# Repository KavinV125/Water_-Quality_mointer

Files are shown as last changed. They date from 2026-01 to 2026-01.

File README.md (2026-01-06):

# 💧 Water Quality Monitoring System

> **Real-time detection of water contamination using IoT & cloud intelligence**

---
KIT
## 📌 Overview

Ensuring access to **safe drinking water** is a critical challenge for industries, institutions, and communities. Water contamination often goes undetected due to **manual testing, delayed lab reports, or fragmented monitoring systems**.  
This project presents an **IoT-enabled Water Quality Monitoring System** that continuously tracks key water quality parameters and provides instant visibility into water safety.

---

## 🚨 Problem Statement

| Challenge | Impact |
|---|---|
| Manual or periodic testing | Delayed contamination detection |
| No real-time monitoring | Health and safety risks |
| Fragmented data systems | Poor decision-making |
| Compliance difficulties | Regulatory violations |
| Reactive response | Operational losses |

---

## 🎯 Key Water Quality Parameters Monitored

| Parameter | Description | Standard Reference |
|---|---|---|
| **pH** | Acidity/alkalinity of water | WHO / BIS |
| **TDS** | Total dissolved solids | WHO / BIS |
| **Turbidity** | Suspended particles & clarity | WHO / BIS |
| **ORP** | Disinfection effectiveness indicator | AWWA / EPA |
## **PH**
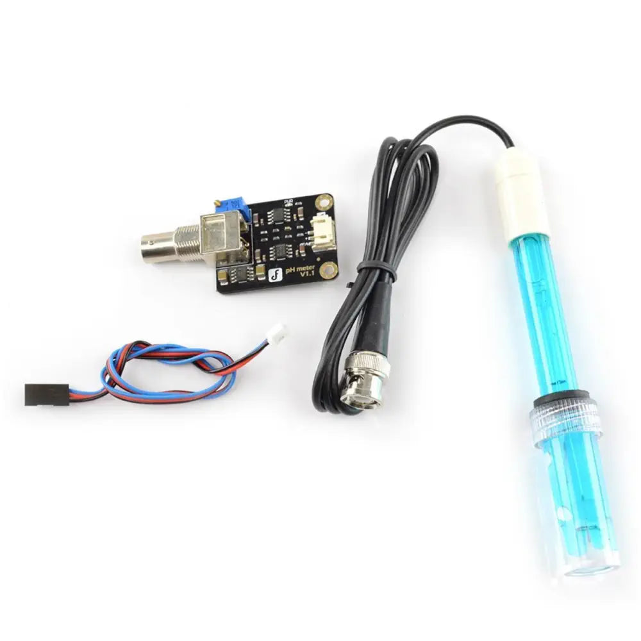
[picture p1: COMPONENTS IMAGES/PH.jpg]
PH


## **TDS**
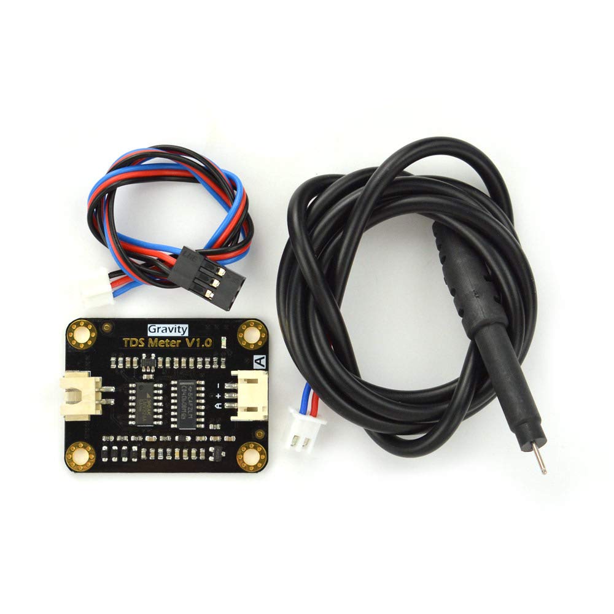
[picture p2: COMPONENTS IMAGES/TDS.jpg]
TDS


## **TURBIDITY**
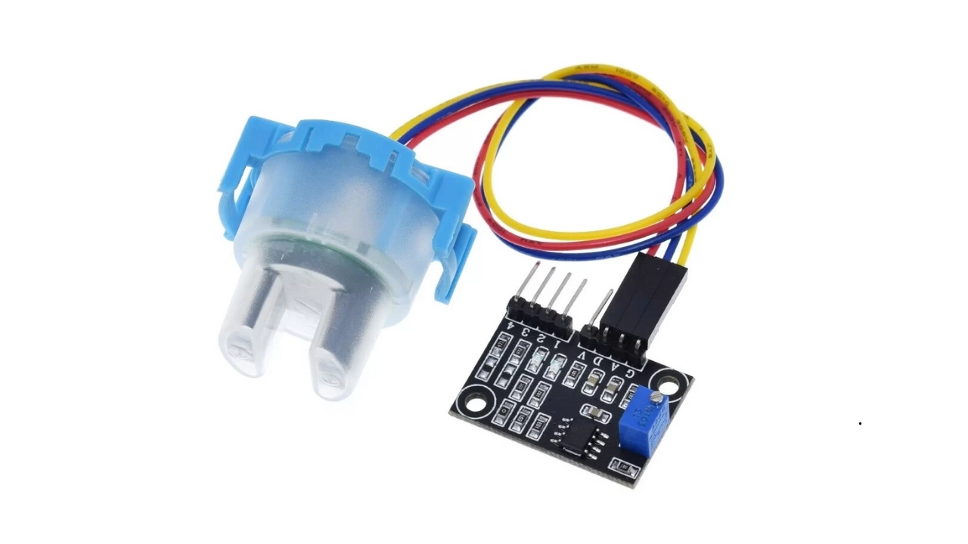
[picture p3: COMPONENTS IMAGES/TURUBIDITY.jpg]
TUR


## **ORP**
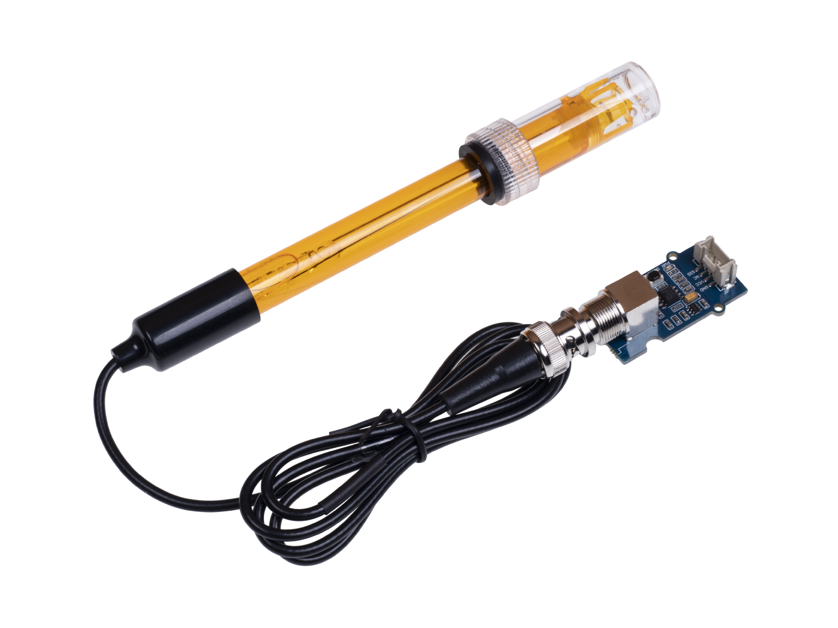
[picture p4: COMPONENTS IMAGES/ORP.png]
ORP


## **RASPBERRY PI 4**

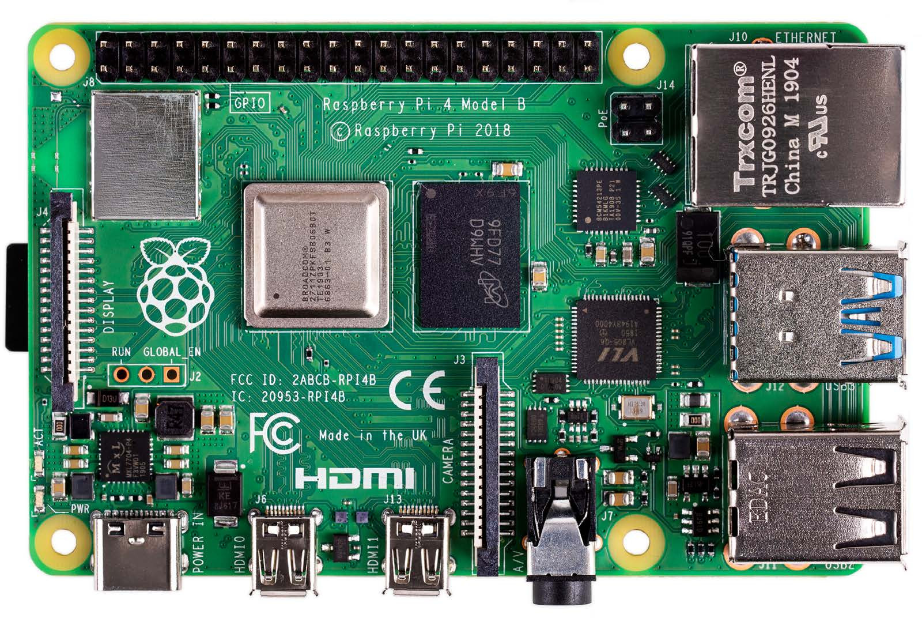
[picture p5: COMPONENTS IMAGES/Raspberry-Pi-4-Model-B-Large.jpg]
PI


## **Sensor placement**
PARAMETERS
---

## 🧠 Concept

The system continuously monitors water quality using **industrial-grade sensors**, processes data using **edge computing (ESP32 / Raspberry Pi)**, and visualizes insights on a **cloud dashboard**.  
Any abnormal value triggers **instant alerts**, enabling proactive intervention.
## **Tech Used :**
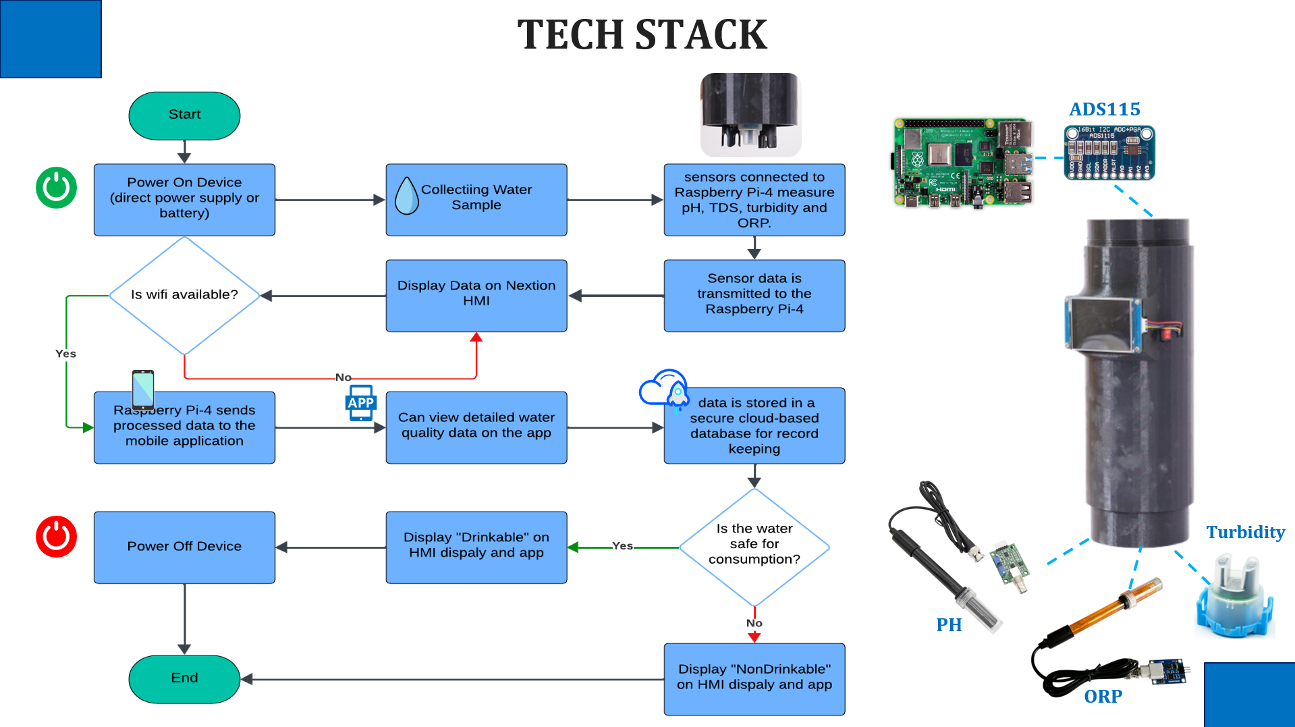
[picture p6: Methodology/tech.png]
TECH

## **Flow**
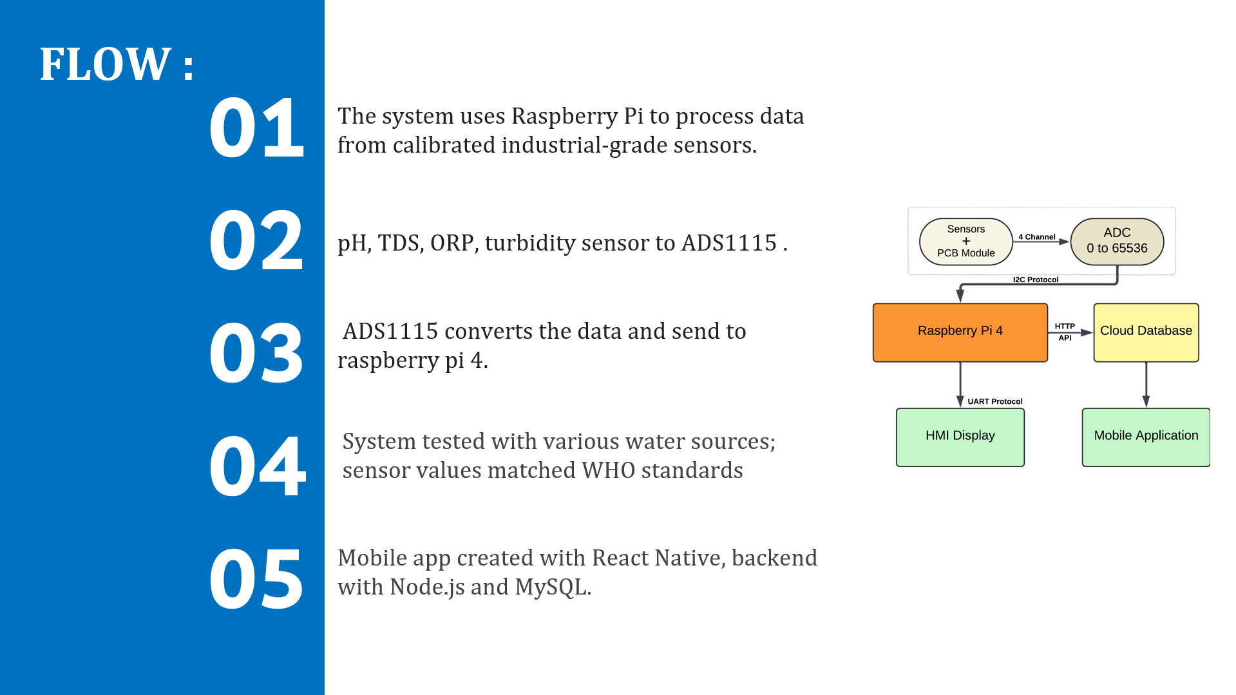
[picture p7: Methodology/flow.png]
flow

---
## **FINAL PRODUCT**
SENSORS

## **OUTPUT**
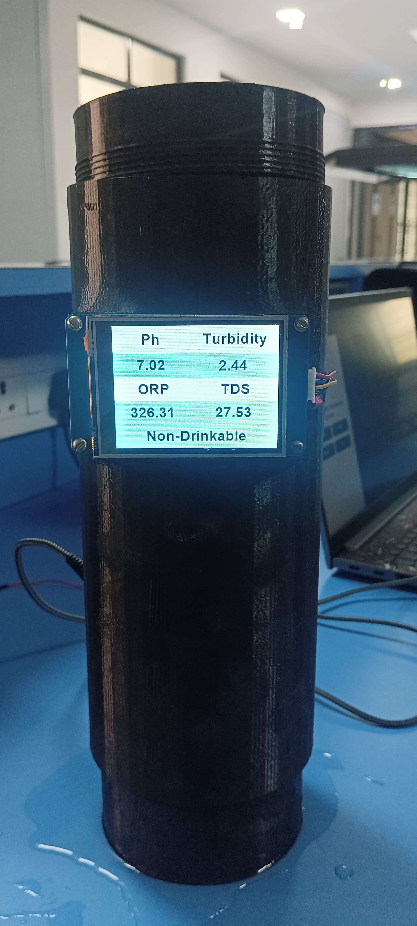
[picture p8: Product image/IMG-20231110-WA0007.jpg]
OUTPUT

## **Web Application UI**

## **Login**
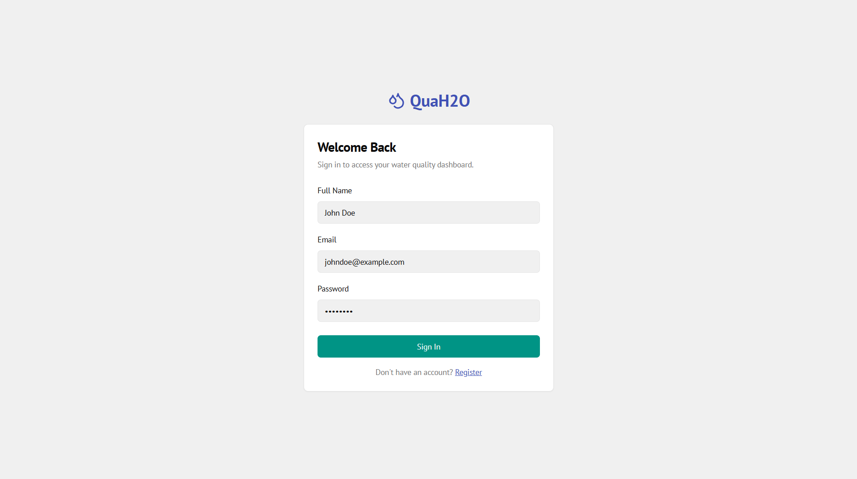
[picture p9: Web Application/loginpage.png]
login


## **Home page**
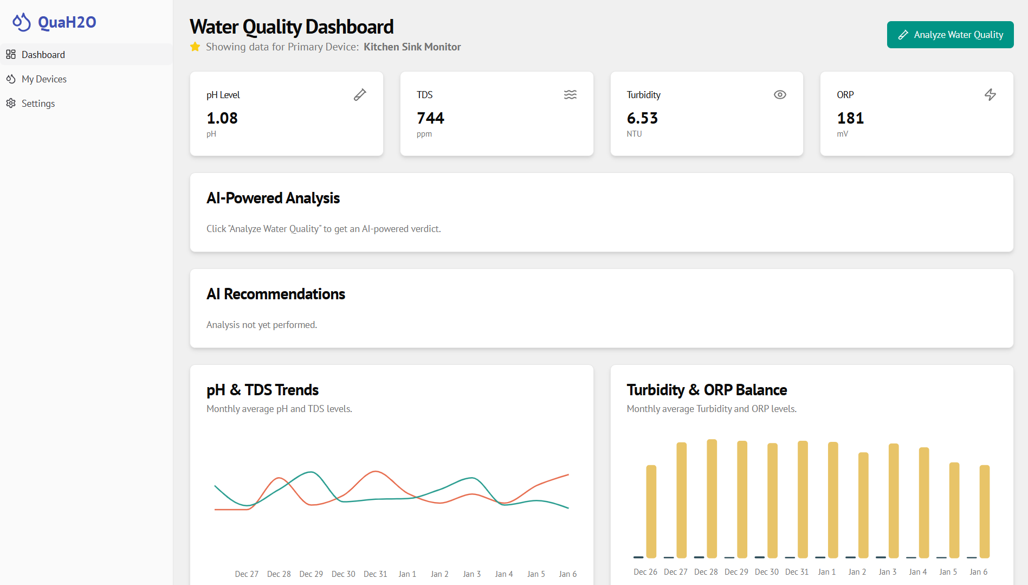
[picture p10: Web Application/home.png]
home


## **Connectivity**
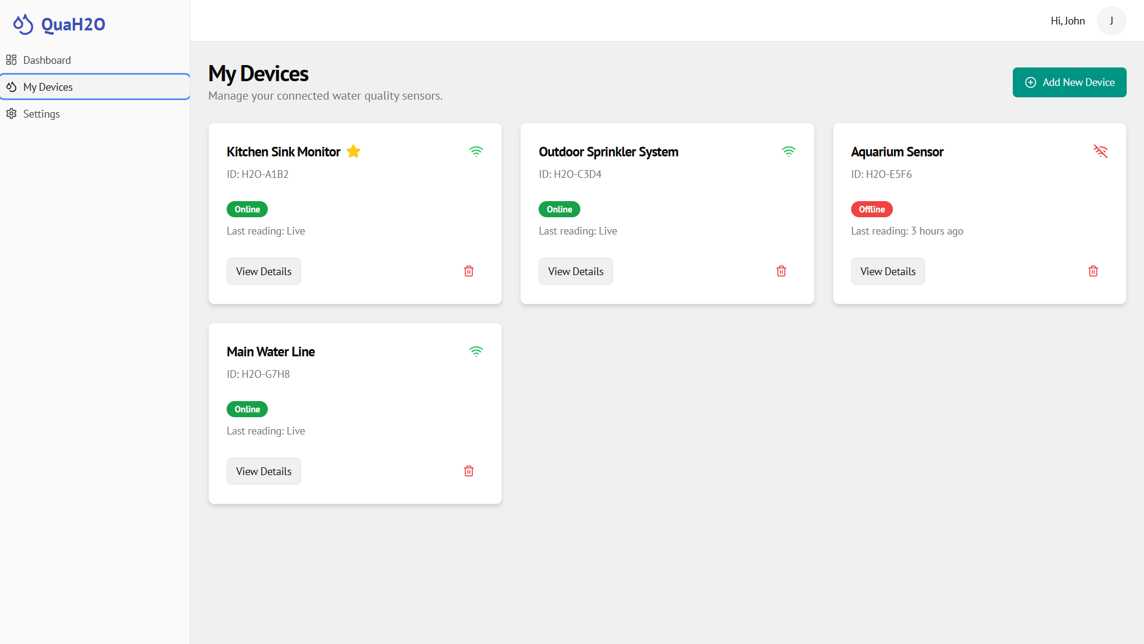
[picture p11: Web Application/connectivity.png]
con

## Final Summary

The Water Quality Monitoring System addresses a critical need for continuous and reliable water safety assurance in both industrial and domestic environments. By combining real-time monitoring of key parameters such as pH, TDS, turbidity, and ORP with IoT-enabled sensing and cloud-based analytics, the system eliminates reliance on slow, manual testing methods. It empowers users to detect contamination instantly, make informed decisions, and maintain compliance with water quality standards. Designed to be scalable, accurate, and user-friendly, this solution contributes to improved public health, operational efficiency, and long-term water sustainability.

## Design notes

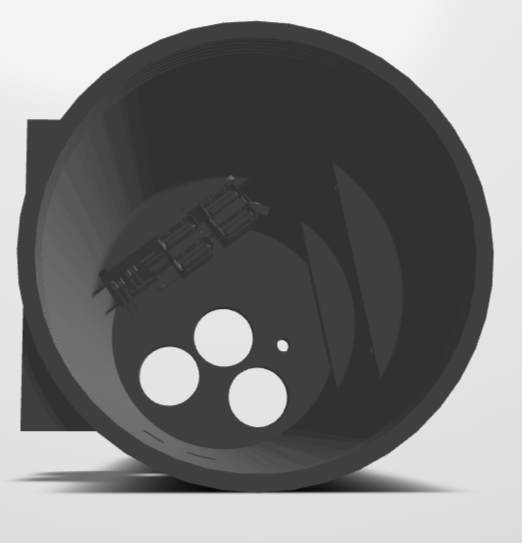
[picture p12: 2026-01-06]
3D Designing/3D image1.png

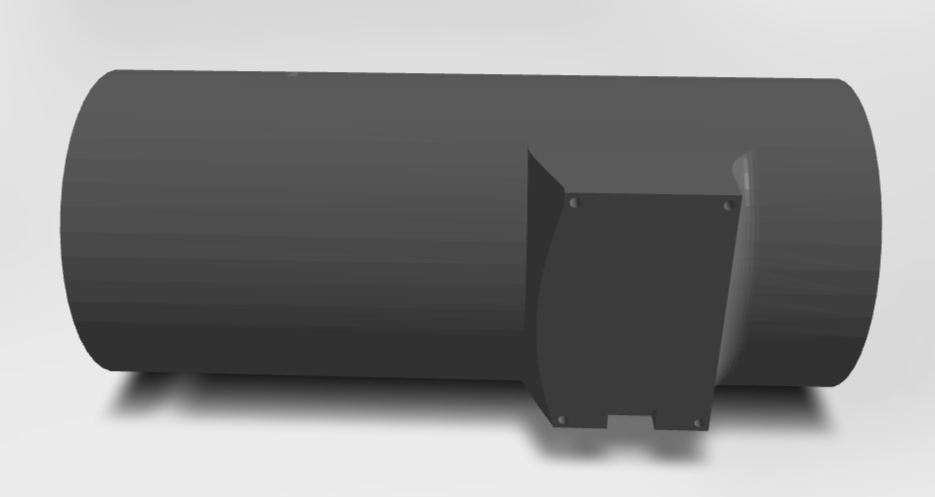
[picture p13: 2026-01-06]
3D Designing/3D image2.png

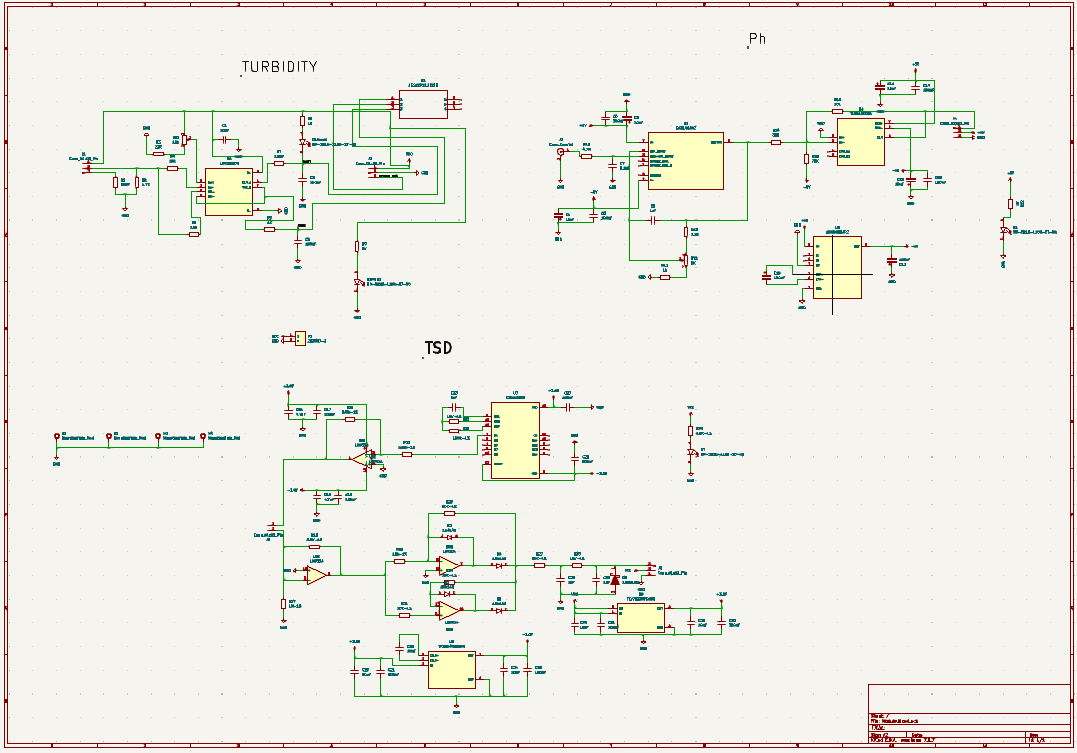
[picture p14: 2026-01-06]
PCB Module/schematic.png

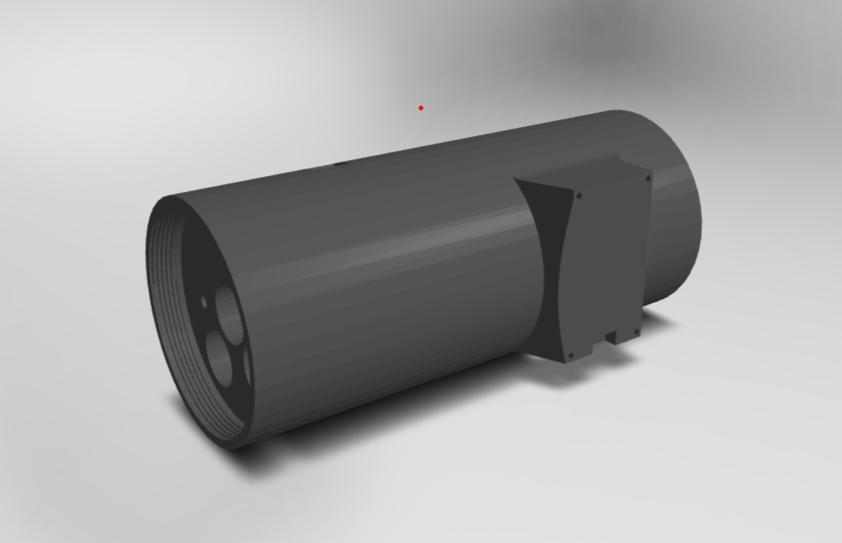
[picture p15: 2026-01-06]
3D Designing/3D image.png

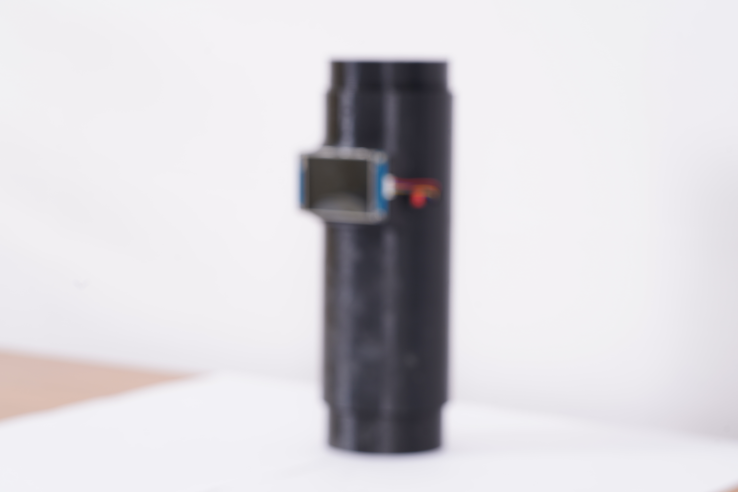
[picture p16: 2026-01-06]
Product image/High Quality Image/SVA02133.JPG

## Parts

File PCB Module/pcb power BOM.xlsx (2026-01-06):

BILL OF MATERIAL
Item | Quantity | Reference | Value | PART TYPE | PCB Footprint | Manufacturer Part Number | Manfacturer Name | Description
1 | 1 | C1 | 10uF | CAP | C_0805_2012Metric | CL21A106KOCLRNC | Samsung Electro-Mechanics | 10 µF ±10% 16V Ceramic Capacitor X5R 0805 (2012 Metric)(3.4mm*1.96mm)
2 | 1 | C4 | 10uF | Polarized CAP | CP_Elec_5x3 | EDK106M035A9BAA | KEMET | 10 µF 35 V Aluminum Electrolytic Capacitors Radial, Can - SMD 2000 Hrs @ 85°C(7.9mm*5.8mm)
3 | 1 | C8 | 10uF | Polarized CAP | CP_Elec_5x3 | EDK106M035A9BAA | KEMET | 10 µF 35 V Aluminum Electrolytic Capacitors Radial, Can - SMD 2000 Hrs @ 85°C(7.9mm*5.8mm)
4 | 1 | C9 | 1uF | CAP | C_0805_2012Metric | CL21B105KAFNNNE | Samsung Electro-Mechanics | 1 µF ±10% 25V Ceramic Capacitor X7R 0805 (2012 Metric)(3.6mm*1.96mm)
5 | 1 | C10 | 100uF | Polaroid CAP | CP_Elec_5x3 | EDK107M035A9HAA | KEMET | 100 µF 35 V Aluminum Electrolytic Capacitors Radial, Can - SMD 2000 Hrs @ 85°C(7.9mm*5.8mm)
6 | 1 | C11 | 10uF | Polarized CAP | CP_Elec_5x3 | EDK106M035A9BAA | KEMET | 10 µF 35 V Aluminum Electrolytic Capacitors Radial, Can - SMD 2000 Hrs @ 85°C(7.9mm*5.8mm)
7 | 1 | C12 | 100uF | Polarized CAP | CP_Elec_5x3 | EDK107M035A9HAA | KEMET | 100 µF 35 V Aluminum Electrolytic Capacitors Radial, Can - SMD 2000 Hrs @ 85°C(7.9mm*5.8mm)
8 | 1 | C13 | 10uF | Polarized CAP | CP_Elec_5x3 | EDK106M035A9BAA | KEMET | 10 µF 35 V Aluminum Electrolytic Capacitors Radial, Can - SMD 2000 Hrs @ 85°C(7.9mm*5.8mm)
9 | 1 | C16 | 4.7uF | CAP | C_0805_2012Metric | CL21A475KAQNNNE | Samsung Electro-Mechanics | 4.7 µF ±10% 25V Ceramic Capacitor X5R 0805 (2012 Metric)(3.4mm*1.96mm)
10 | 1 | C18 | 4.7uF | CAP | C_0805_2012Metric | CL21A475KAQNNNE | Samsung Electro-Mechanics | 4.7 µF ±10% 25V Ceramic Capacitor X5R 0805 (2012 Metric)(3.4mm*1.96mm)
11 | 1 | C20 | 10uF | CAP | C_0805_2012Metric | CL21A106KOCLRNC | Samsung Electro-Mechanics | 10 µF ±10% 16V Ceramic Capacitor X5R 0805 (2012 Metric)(3.4mm*1.96mm)
12 | 1 | C22 | 10uF | CAP | C_0805_2012Metric | CL21A106KOCLRNC | Samsung Electro-Mechanics | 10 µF ±10% 16V Ceramic Capacitor X5R 0805 (2012 Metric)(3.4mm*1.96mm)
13 | 1 | C24 | 10uF | CAP | C_0805_2012Metric | CL21A106KOCLRNC | Samsung Electro-Mechanics | 10 µF ±10% 16V Ceramic Capacitor X5R 0805 (2012 Metric)(3.4mm*1.96mm)
14 | 1 | C26 | 1uF | CAP | C_0805_2012Metric | CL21B105KAFNNNE | Samsung Electro-Mechanics | 1 µF ±10% 25V Ceramic Capacitor X7R 0805 (2012 Metric)(3.4mm*1.96mm)
15 | 1 | C29 | 10uF | CAP | C_0805_2012Metric | CL21A106KOCLRNC | Samsung Electro-Mechanics | 10 µF ±10% 16V Ceramic Capacitor X5R 0805 (2012 Metric)(3.4mm*1.96mm)
16 | 1 | C30 | 1uF | CAP | C_0805_2012Metric | CL21B105KAFNNNE | Samsung Electro-Mechanics | 1 µF ±10% 25V Ceramic Capacitor X7R 0805 (2012 Metric)(3.4mm*1.96mm)
17 | 1 | C32 | 10uF | CAP | C_0805_2012Metric | CL21A106KOCLRNC | Samsung Electro-Mechanics | 10 µF ±10% 16V Ceramic Capacitor X5R 0805 (2012 Metric)(3.4mm*1.96mm)
18 | 1 | R1 | 500R | RES | Resistor_SMD:R_0402_2012Metric | PNM0402E5000BST1 | Vishay Dale Thin Film | 500 Ohms ±0.1% 0.05W, 1/20W Chip Resistor 0402 (1005 Metric) Anti-Sulfur, Moisture Resistant, Non-Inductive, Non-Magnetic Thin Film(3.36mm*1.9mm)
19 | 1 | R2 | 4.7K | RES | Resistor_SMD:R_0805_2012Metric | RC0805JR-074K7L | YAGEO | 4.7 kOhms ±5% 0.125W, 1/8W Chip Resistor 0805 (2012 Metric) Moisture Resistant Thick Film
20 | 1 | R3 | 22 ohm | RES | Resistor_SMD:R_0805_2012Metric | RC0805JR-0722RL | YAGEO | 22 Ohms ±5% 0.125W, 1/8W Chip Resistor 0805 (2012 Metric) Moisture Resistant Thick Film(3.36mm*1.9mm)
21 | 1 | R4 | 10K | RES | Resistor_SMD:R_0805_2012Metric | RC0805JR-0710KL | YAGEO | 10 kOhms ±5% 0.125W, 1/8W Chip Resistor 0805 (2012 Metric) Moisture Resistant Thick Film(3.36mm*1.9mm)
22 | 1 | R5 | 10K | RES | Resistor_SMD:R_0805_2012Metric | RC0805JR-0710KL | YAGEO | 10 kOhms ±5% 0.125W, 1/8W Chip Resistor 0805 (2012 Metric) Moisture Resistant Thick Film(3.36mm*1.9mm)
23 | 1 | R6 | 1K | RES | Resistor_SMD:R_0805_2012Metric | RNCP0805FTD1K00 | Stackpole Electronics Inc | 1 kOhms ±1% 0.25W, 1/4W Chip Resistor 0805 (2012 Metric) Anti-Sulfur Thin Film(3.36mm*1.9mm)
24 | 1 | R7 | 100R | RES | Resistor_SMD:R_0805_2012Metric | RN73C2A100RBTDF | TE Connectivity Passive Product | 100 Ohms ±0.1% 0.1W, 1/10W Chip Resistor 0805 (2012 Metric) Thin Film(3.36mm*1.9mm)
25 | 1 | R8 | 1K | RES | Resistor_SMD:R_0805_2012Metric | RNCP0805FTD1K00 | Stackpole Electronics Inc | 1 kOhms ±1% 0.25W, 1/4W Chip Resistor 0805 (2012 Metric) Anti-Sulfur Thin Film(3.36mm*1.9mm)
26 | 1 | R9 | 1K | RES | Resistor_SMD:R_0805_2012Metric | RNCP0805FTD1K00 | Stackpole Electronics Inc | 1 kOhms ±1% 0.25W, 1/4W Chip Resistor 0805 (2012 Metric) Anti-Sulfur Thin Film(3.36mm*1.9mm)
27 | 1 | R10 | 4.7M | RES | Resistor_SMD:R_0805_2012Metric | RC0805JR-074M7L | YAGEO | 4.7 MOhms ±5% 0.125W, 1/8W Chip Resistor 0805 (2012 Metric) Moisture Resistant Thick Film(3.36mm*1.9mm)
28 | 1 | R11 | 1K | RES | Resistor_SMD:R_0805_2012Metric | RNCP0805FTD1K00 | Stackpole Electronics Inc | 1 kOhms ±1% 0.25W, 1/4W Chip Resistor 0805 (2012 Metric) Anti-Sulfur Thin Film(3.36mm*1.9mm)
29 | 1 | R12 | 1K | RES | Resistor_SMD:R_0805_2012Metric | RNCP0805FTD1K00 | Stackpole Electronics Inc | 1 kOhms ±1% 0.25W, 1/4W Chip Resistor 0805 (2012 Metric) Anti-Sulfur Thin Film(3.36mm*1.9mm)
30 | 1 | R13 | 2.2K | RES | Resistor_SMD:R_0805_2012Metric | RC0805JR-072K2L | YAGEO | 2.2 kOhms ±5% 0.125W, 1/8W Chip Resistor 0805 (2012 Metric) Moisture Resistant Thick Film(3.36mm*1.9mm)
31 | 1 | R14 | 30K | RES | Resistor_SMD:R_0805_2012Metric | RC0805JR-0730KL | YAGEO | 30 kOhms ±5% 0.125W, 1/8W Chip Resistor 0805 (2012 Metric) Moisture Resistant Thick Film(3.36mm*1.9mm)
32 | 1 | R15 | 75K | RES | Resistor_SMD:R_0805_2012Metric | RC0805JR-0775KL | YAGEO | 75 kOhms ±5% 0.125W, 1/8W Chip Resistor 0805 (2012 Metric) Moisture Resistant Thick Film(3.36mm*1.9mm)
33 | 1 | R16 | 30K | RES | Resistor_SMD:R_0805_2012Metric | RC0805JR-0730KL | YAGEO | 30 kOhms ±5% 0.125W, 1/8W Chip Resistor 0805 (2012 Metric) Moisture Resistant Thick Film(3.36mm*1.9mm)
34 | 1 | R17 | 1M-1% | RES-1%Tolerence | Resistor_SMD:R_0805_2012Metric | CRG0805F1M0 | TE Connectivity Passive Product | 1 MOhms ±1% 0.125W, 1/8W Chip Resistor 0805 (2012 Metric) Thick Film(3.36mm*1.9mm)
35 | 1 | R18 | 5.6K-1% | RES-1%Tolerence | Resistor_SMD:R_0805_2012Metric | RMCF0805FT5K60 | Stackpole Electronics Inc | 5.6 kOhms ±1% 0.125W, 1/8W Chip Resistor 0805 (2012 Metric) Automotive AEC-Q200 Thick Film(3.36mm*1.9mm)
36 | 1 | R19 | 6.8K-1% | RES-1%Tolerence | Resistor_SMD:R_0805_2012Metric | RMCF0805FT6K80 | Stackpole Electronics Inc | 6.8 kOhms ±1% 0.125W, 1/8W Chip Resistor 0805 (2012 Metric) Automotive AEC-Q200 Thick Film
37 | 1 | R20 | 10K-1% | RES-1%Tolerence | Resistor_SMD:R_0805_2012Metric | RMCF0805FT10K0 | Stackpole Electronics Inc | 10 kOhms ±1% 0.125W, 1/8W Chip Resistor 0805 (2012 Metric) Automotive AEC-Q200 Thick Film
38 | 1 | R21 | 10K-1% | RES-1%Tolerence | Resistor_SMD:R_0805_2012Metric | RMCF0805FT10K0 | Stackpole Electronics Inc | 10 kOhms ±1% 0.125W, 1/8W Chip Resistor 0805 (2012 Metric) Automotive AEC-Q200 Thick Film
39 | 1 | R22 | 100K-1% | RES-1%Tolerence | Resistor_SMD:R_0805_2012Metric | RMCF0805FT100K | Stackpole Electronics Inc | 100 kOhms ±1% 0.125W, 1/8W Chip Resistor 0805 (2012 Metric) Automotive AEC-Q200 Thick Film
40 | 1 | R23 | 10K-1% | RES-1%Tolerence | Resistor_SMD:R_0805_2012Metric | RMCF0805FT10K0 | Stackpole Electronics Inc | 10 kOhms ±1% 0.125W, 1/8W Chip Resistor 0805 (2012 Metric) Automotive AEC-Q200 Thick Film
41 | 1 | R24 | 10K-1% | RES-1%Tolerence | Resistor_SMD:R_0805_2012Metric | RMCF0805FT10K0 | Stackpole Electronics Inc | 10 kOhms ±1% 0.125W, 1/8W Chip Resistor 0805 (2012 Metric) Automotive AEC-Q200 Thick Film
42 | 1 | R25 | 10K-1% | RES-1%Tolerence | Resistor_SMD:R_0805_2012Metric | RMCF0805FT10K0 | Stackpole Electronics Inc | 10 kOhms ±1% 0.125W, 1/8W Chip Resistor 0805 (2012 Metric) Automotive AEC-Q200 Thick Film
43 | 1 | R26 | 100K-1% | RES-1%Tolerence | Resistor_SMD:R_0805_2012Metric | RMCF0805FT100K | Stackpole Electronics Inc | 100 kOhms ±1% 0.125W, 1/8W Chip Resistor 0805 (2012 Metric) Automotive AEC-Q200 Thick Film
44 | 1 | R27 | 10K-1% | RES-1%Tolerence | Resistor_SMD:R_0805_2012Metric | RMCF0805FT10K0 | Stackpole Electronics Inc | 10 kOhms ±1% 0.125W, 1/8W Chip Resistor 0805 (2012 Metric) Automotive AEC-Q200 Thick Film
45 | 1 | R28 | 10K-1% | RES-1%Tolerence | Resistor_SMD:R_0805_2012Metric | RMCF0805FT10K0 | Stackpole Electronics Inc | 10 kOhms ±1% 0.125W, 1/8W Chip Resistor 0805 (2012 Metric) Automotive AEC-Q200 Thick Film
46 | 1 | R29 | 5.6K-1% | RES-1%Tolerence | Resistor_SMD:R_0805_2012Metric | RMCF0805FT5K60 | Stackpole Electronics Inc | 5.6 kOhms ±1% 0.125W, 1/8W Chip Resistor 0805 (2012 Metric) Automotive AEC-Q200 Thick Film
47 | 1 | RV1 | 10K | Terminal | Potentiometer_ACP_CA9-V10_Vertical | 3362P-1-103LF | Bourns Inc. | 10 kOhms 0.5W, 1/2W PC Pins Through Hole Trimmer Potentiometer Cermet 1.0 Turn Top Adjustment(12.9mm*10.35mm)
48 | 1 | RV2 | 5K | Terminal | Potentiometer_ACP_CA9-V10_Vertical | 3386P-1-502LF | Bourns Inc. | 5 kOhms 0.5W, 1/2W PC Pins Through Hole Trimmer Potentiometer Cermet 1.0 Turn Top Adjustment(12.9mm*10.35mm)
49 | 1 | D1 | LED | White led SMD | LED_SMD:LED_0805_2012Metric | MP-2016-1100-27-90 | Luminus Devices Inc. | LED Lighting MP-2016 White, Warm 2700K 3V 60mA 110° 0806 (2016 Metric)(2.965mm*1.46mm)
50 | 1 | D1Dout1 | LED | White led SMD | LED_SMD:LED_0805_2012Metric | MP-2016-1100-27-90 | Luminus Devices Inc. | LED Lighting MP-2016 White, Warm 2700K 3V 60mA 110° 0806 (2016 Metric)(2.965mm*1.46mm)
51 | 1 | D2PWM1 | LED | White led SMD | LED_SMD:LED_0805_2012Metric | MP-2016-1100-27-90 | Luminus Devices Inc. | LED Lighting MP-2016 White, Warm 2700K 3V 60mA 110° 0806 (2016 Metric)
52 | 1 | D6 | 1N5819W | Diode | KiCad1N5819W:SODFL3618X110N | 1N5819W | SMC Diode Solutions | DIODE SCHOTTKY 40V 1A SOD123FL
53 | 1 | D7 | LED | White led SMD | LED_SMD:LED_0805_2012Metric | MP-2016-1100-27-90 | Luminus Devices Inc. | LED Lighting MP-2016 White, Warm 2700K 3V 60mA 110° 0806 (2016 Metric)
54 | 1 | J1 | Conn_01x03_pin | Male Berg Strip | Connector_PinHeader_1.00mm:PinHeader_1x03_P1.00mm_Vertical | Male Berg Strip | Male Berg Strip | Male Berg Strip
55 | 1 | J2 | Conn_01x03_pin | Male Berg Strip | Connector_PinHeader_1.00mm:PinHeader_1x03_P1.00mm_Vertical | Male Berg Strip | Male Berg Strip | Male Berg Strip
56 | 1 | J3 | Conn_Coaxial | Ph connector | Connector_Coaxial:BNC_Amphenol_B6252HB-NPP3G-50_Horizontal | 731375003 | Molex | BNC Connector Jack, Female Socket 50 Ohms Panel Mount, Through Hole, Right Angle Solder
57 | 1 | J4 | Conn_01x03_pin | Female Berg Strip | Connector_PinSocket_2.54mm:PinSocket_1x03_P2.54mm_Vertical | Female Berg Strip | Female Berg Strip | Female Berg Strip
58 | 1 | J5 | Conn_01x02_pin | Male Berg Strip | Connector_PinHeader_2.54mm:PinHeader_1x02_P2.54mm_Vertical | Male Berg Strip | Male Berg Strip | Male Berg Strip
59 | 1 | J6 | Conn_01x03_pin | Male Berg Strip | Connector_PinHeader_2.54mm:PinHeader_1x02_P2.54mm_Vertical | Male Berg Strip | Male Berg Strip | Male Berg Strip
60 | 1 | U1 | LMV358IDR | IC 8 PIN | Package_CSP:LFCSP-8_2x2mm_P0.5mm | LMV358IDR | Texas Instruments (https://www.digikey.in/en/supplier-centers/texas-instruments) | IC OPAMP GP 2 CIRCUIT 8SOIC, General Purpose Amplifier 2 Circuit Rail-to-Rail 8-SOIC
61 | 1 | U2 | CA3140AMZ | IC 8 PIN | CA3140AMZ:SOIC127P600X175-8N | CA3140AMZ | Renesas Electronics America Inc | (CA3140AMZ)General Purpose Amplifier 1 Circuit 8-SOIC
62 | 1 | U3 | ADM8660AMZ | IC 8 PIN | ADM8660ARZ:SOIC127P600X175-8N | ADM8660ARZ | Analog Devices Inc. (https://www.digikey.in/en/supplier-centers/analog-devices) | Charge Pump Switching Regulator IC Negative Fixed -Vin 1 Output 100mA 8-SOIC (0.154", 3.90mm Width)
63 | 1 | U4 | TL081BCDG4 | IC 8 PIN | TL081BCDG4:SOIC127P599X175-8N | TL081BCD | Texas Instruments | (TL081BCDG4)J-FET Amplifier 1 Circuit 8-SOIC
64 | 1 | U5 | LMV324 | IC 14 PIN | Package_SO:SOIC-14_3.9x8.7mm_P1.27mm | LMV324IDT | STMicroelectronics | IC OPAMP GP 4 CIRCUIT 14SO
65 | 1 | U6 | TPS60400DBVR | IC 5 PIN | TPS60400DBVR:SOT95P280X145-5N | TLV73330PDBVR | Texas Instruments (https://www.digikey.in/en/supplier-centers/texas-instruments) | Linear Voltage Regulator IC Positive Fixed 1 Output 300mA SOT-23-5
66 | 1 | U7 | CD4060BM | IC 16 PIN | CD4060BM:SOIC127P600X175-16N | CD4060BM | Texas Instruments | IC BINARY COUNTER 14-BIT 16SOIC
67 | 1 | U8 | TLV73330PDBVR | IC 5PIN | TLV73330PDBVR:SOT95P280X145-5N | TLV73330PDBVR | Texas Instruments | Linear Voltage Regulator IC Positive Fixed 1 Output 300mA SOT-23-5
68 | 1 | S1 | SW_DPDT_x2 | 8 PIN SWITCH | Button_Switch_SMD:SW_DPDT_CK_JS202011JCQN | JS202011CQN | C&K | Slide Switch DPDT Through Hole
69 | 1 | P1 | 282837-2 | GREEN CONN THT | 282837-2:TE_282837-2 | GREEN CONN THT | GREEN CONN THT | GREEN CONN THT
70 | 1 | C3 | 100nF | CAP | C_0805_2012Metric | MT05B104M500BD | Aillen | 0.1 µF ±20% 50V Ceramic Capacitor X7R 0805 (2012 Metric)
71 | 1 | C2 | 100nF | CAP | C_0805_2012Metric | MT05B104M500BD | Aillen | 0.1 µF ±20% 50V Ceramic Capacitor X7R 0805 (2012 Metric)
72 | 1 | C5 | 100nF | CAP | C_0805_2012Metric | MT05B104M500BD | Aillen | 0.1 µF ±20% 50V Ceramic Capacitor X7R 0805 (2012 Metric)
73 | 1 | C6 | 100nF | CAP | C_0805_2012Metric | MT05B104M500BD | Aillen | 0.1 µF ±20% 50V Ceramic Capacitor X7R 0805 (2012 Metric)
74 | 1 | C14 | 100nF | CAP | C_0805_2012Metric | MT05B104M500BD | Aillen | 0.1 µF ±20% 50V Ceramic Capacitor X7R 0805 (2012 Metric)
75 | 1 | C15 | 100nF | CAP | C_0805_2012Metric | MT05B104M500BD | Aillen | 0.1 µF ±20% 50V Ceramic Capacitor X7R 0805 (2012 Metric)
76 | 1 | C17 | 100nF | CAP | C_0805_2012Metric | MT05B104M500BD | Aillen | 0.1 µF ±20% 50V Ceramic Capacitor X7R 0805 (2012 Metric)
77 | 1 | C25 | 100nF | CAP | C_0805_2012Metric | MT05B104M500BD | Aillen | 0.1 µF ±20% 50V Ceramic Capacitor X7R 0805 (2012 Metric)
78 | 1 | C19 | 100nF | CAP | C_0805_2012Metric | MT05B104M500BD | Aillen | 0.1 µF ±20% 50V Ceramic Capacitor X7R 0805 (2012 Metric)
79 | 1 | C21 | 100nF | CAP | C_0805_2012Metric | MT05B104M500BD | Aillen | 0.1 µF ±20% 50V Ceramic Capacitor X7R 0805 (2012 Metric)
80 | 1 | C27 | 100nF | CAP | C_0805_2012Metric | MT05B104M500BD | Aillen | 0.1 µF ±20% 50V Ceramic Capacitor X7R 0805 (2012 Metric)
81 | 1 | C28 | 100nF | CAP | C_0805_2012Metric | MT05B104M500BD | Aillen | 0.1 µF ±20% 50V Ceramic Capacitor X7R 0805 (2012 Metric)
82 | 1 | C31 | 100nF | CAP | C_0805_2012Metric | MT05B104M500BD | Aillen | 0.1 µF ±20% 50V Ceramic Capacitor X7R 0805 (2012 Metric)
83 | 1 | C33 | 100nF | CAP | C_0805_2012Metric | MT05B104M500BD | Aillen | 0.1 µF ±20% 50V Ceramic Capacitor X7R 0805 (2012 Metric)
84 | 1 | C23 | 1nF | CAP | C_0805_2012Metric | C0805C102KDRACAUTO | KEMET | 1000 pF ±10% 1000V (1kV) Ceramic Capacitor X7R 0805 (2012 Metric)
85 | 1 | C7 | 2.2nF | CAP | C_0805_2012Metric | C0805C222K3GEC7800 | KEMET | 2200 pF ±10% 25V Ceramic Capacitor C0G, NP0 0805 (2012 Metric)
86 | 1 | D3 | 1N4148 | Diode | 1N4148:DIOAD829W49L456D191 | 1N4148 | onsemi | Diode 100 V 200mA Through Hole DO-35
87 | 1 | D4 | 1N4149 | Diode | 1N4148:DIOAD829W49L456D192 | 1N4149 | onsemi | Diode 100 V 200mA Through Hole DO-35
88 | 1 | D5 | 1N4150 | Diode | 1N4148:DIOAD829W49L456D193 | 1N4150 | onsemi | Diode 100 V 200mA Through Hole DO-35
89 | 1 | D2 | 1N4151 | Diode | 1N4148:DIOAD829W49L456D194 | 1N4151 | onsemi | Diode 100 V 200mA Through Hole DO-35

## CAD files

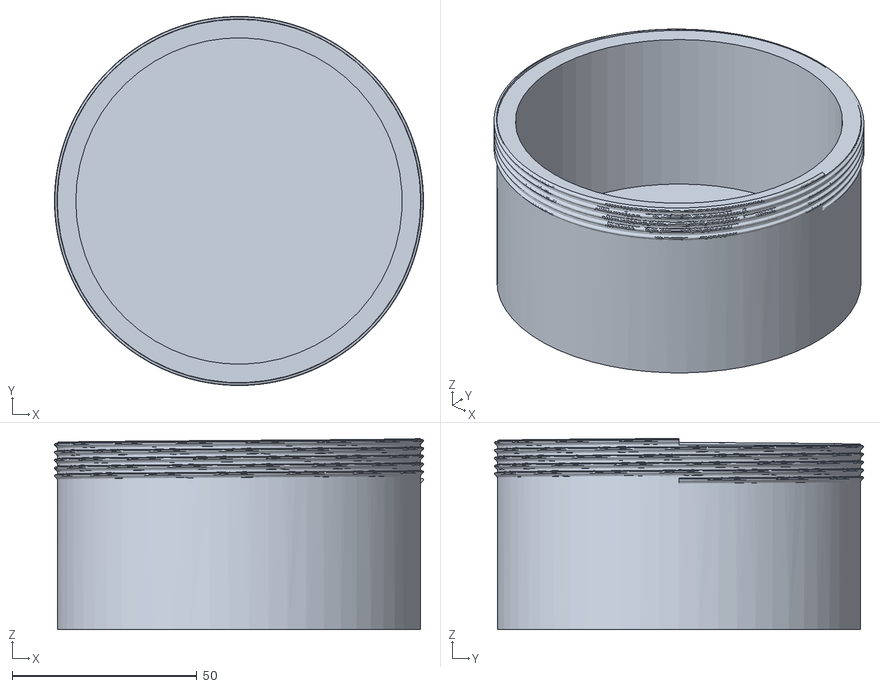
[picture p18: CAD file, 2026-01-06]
3D Designing/bottom cup.STL
99.9 x 99.9 x 51.7

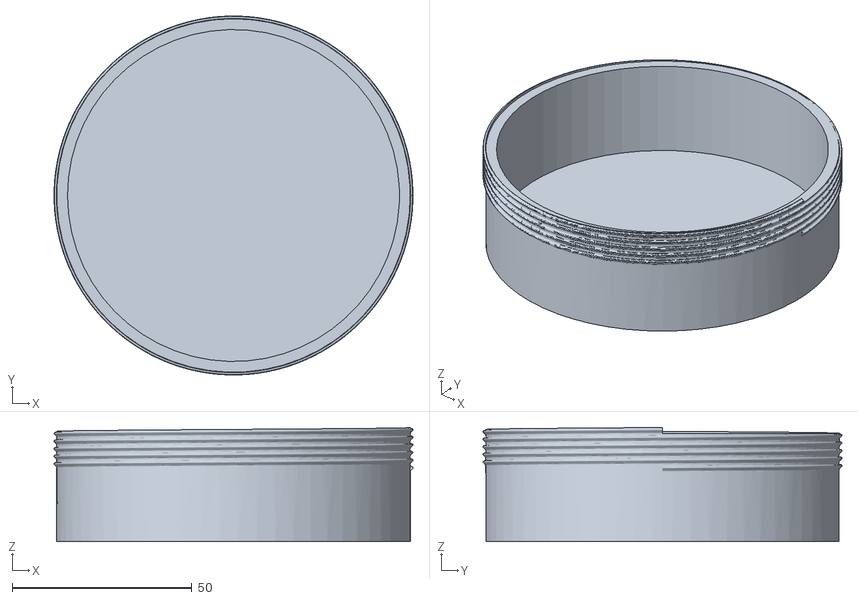
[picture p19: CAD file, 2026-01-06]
3D Designing/top cap.STL
99.9 x 99.9 x 31.7

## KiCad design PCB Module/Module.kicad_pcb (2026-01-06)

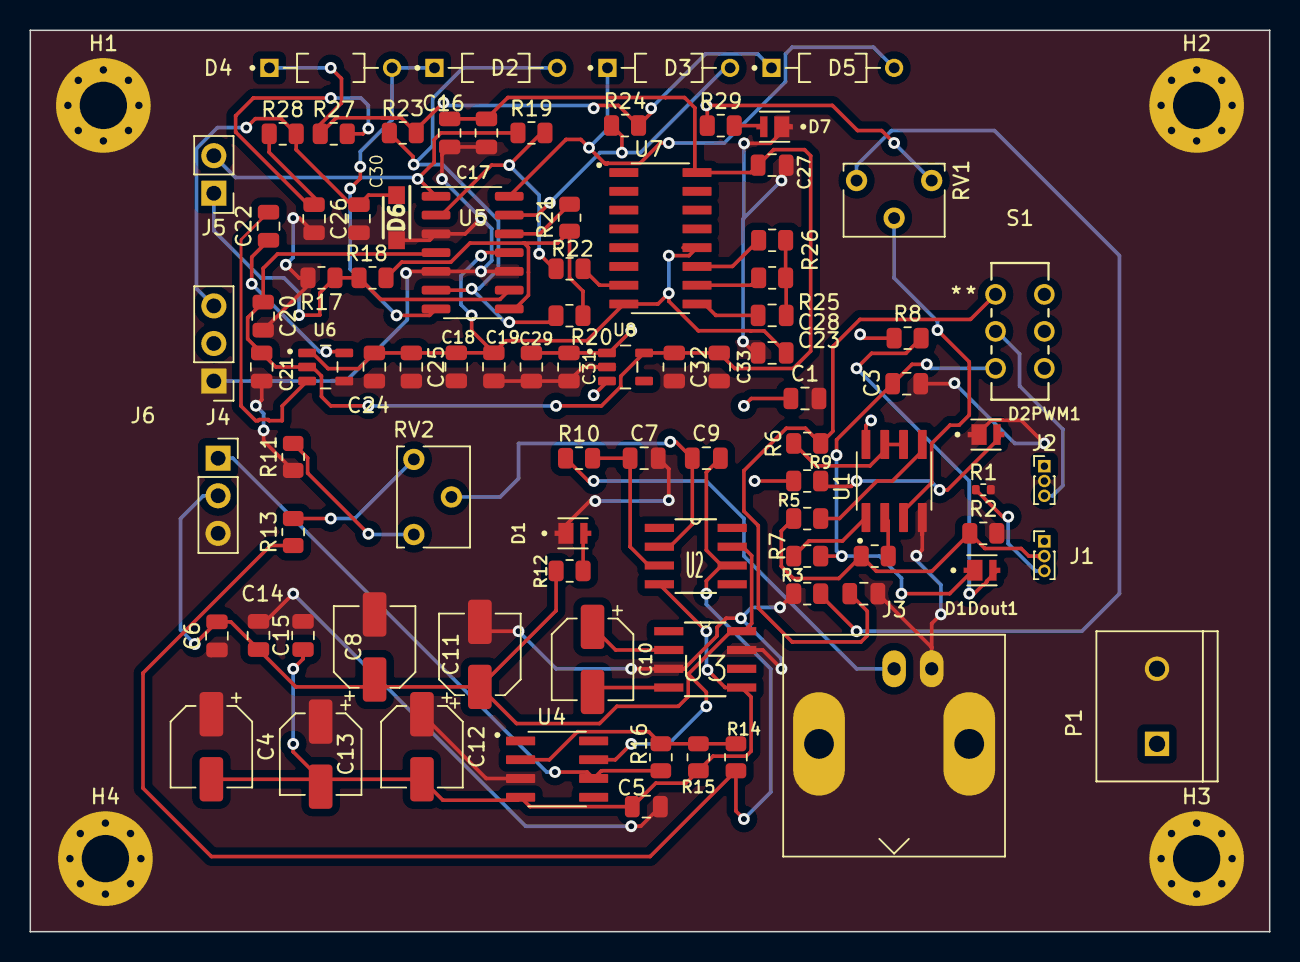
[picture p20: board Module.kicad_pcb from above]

Board: 2 copper layers, 83.8 x 61.0 mm, 93 parts (0 on the bottom side), 50 nets.

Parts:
C1, C20, C22, C24, C29, C32: 10uF; C_0805_2012Metric
C2, C3, C5, C6, C14, C15, C17, C19, C21, C25, C27, C28, C31, C33: 100nF; C_0805_2012Metric
C4, C8, C11, C13: 10uF; CP_Elec_5x3
C7: 2.2nF; C_0805_2012Metric
C9, C26, C30: 1uF; C_0805_2012Metric
C10, C12: 100uF; CP_Elec_5x3
C16, C18: 4.7uF; C_0805_2012Metric
C23: 1nF; C_0805_2012Metric
D1, D1Dout1, D2PWM1, D7: MP-2016-1100-27-90; LED_MP-2016-1100-27-90
D2, D3, D4, D5: 1N4148; DIOAD829W49L456D191
D6: 1N5819W; SODFL3618X110N
H1, H2, H3, H4: MountingHole_Pad; MountingHole_3.2mm_M3_Pad_Via
J1, J2: Conn_01x03_Pin; PinHeader_1x03_P1.00mm_Vertical
J3: Conn_Coaxial; BNC_Amphenol_B6252HB-NPP3G-50_Horizontal
J4: Conn_01x03_Pin; PinSocket_1x03_P2.54mm_Vertical
J5: Conn_01x02_Pin; PinHeader_1x02_P2.54mm_Vertical
J6: Conn_01x03_Pin; PinHeader_1x03_P2.54mm_Vertical
P1: 282837-2; TE_282837-2
R1: 500R; R_0402_1005Metric
R2: 4.7K; R_0805_2012Metric
R3: 22R; R_0805_2012Metric
R4, R5: 10K; R_0805_2012Metric
R6, R8, R9, R12: 1K; R_0805_2012Metric
R7: 100R; R_0805_2012Metric
R10: 4.7M; R_0805_2012Metric
R11: 1k; R_0805_2012Metric
R13: 2.2K; R_0805_2012Metric
R14, R16: 30K; R_0805_2012Metric
R15: 75K; R_0805_2012Metric
R17: 1M-1%; R_0805_2012Metric
R18, R29: 5.6K-1%; R_0805_2012Metric
R19: 6.8K-1%; R_0805_2012Metric
R20, R21, R23, R24, R25, R27, R28: 10K-1%; R_0805_2012Metric
R22, R26: 100K-1%; R_0805_2012Metric
RV1: 10K; Potentiometer_Vishay_T73XX_Horizontal
RV2: 5K; Potentiometer_Vishay_T73XX_Horizontal
S1: JS202011CQN; SWITCH_011CQN
U1: LMV358IDR; SOIC127P599X175-8N
U2: CA3140AMZ; SOIC127P600X175-8N
U3: ADM8660ARZ; SOIC127P600X175-8N
U4: TL081BCDG4; SOIC127P599X175-8N
U5: LMV324; SOIC-14_3.9x8.7mm_P1.27mm
U6: TPS60400DBVR; SOT95P280X145-5N
U7: CD4060BM; SOIC127P600X175-16N
U8: TLV73330PDBVR; SOT95P280X145-5N

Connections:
+3.0V: C16.1, C17.1, C20.1, C21.1, C27.1, C32.1, C33.1, U5.4 (V+), U6.2 (IN), U7.16 (VCC), U8.5 (OUT)
+5V: C6.2, C8.1, C11.1, C14.1, J4.2, R12.1, U2.7 (V+), U3.8 (V+), U4.7 (VCC+)
-3.0V: C18.1, C19.1, C24.1, C25.1, C28.2, U5.11 (V-), U6.1 (OUT), U7.8 (GND), U7.12 (RESET)
-5V: C4.2, C5.1, C12.2, C13.2, C15.1, R15.2, U2.4 (V-), U3.5 (OUT), U4.4 (VCC-)
/Dout: C3.1, D1Dout1.C, R7.2, S1.3
/sensor_out: J2.3, S1.2
GND: C1.2, C2.2, C3.2, C4.1, C5.2, C6.1, C7.2, C8.2, C11.2, C12.1, C13.1, C14.2, C15.2, C16.2, C17.2, C18.2, C19.2, C20.2, C21.2, C24.2, C25.2, C26.2, C27.2, C28.1, C29.2, C30.2, C31.2, C32.2, C33.2, D1.C, D2PWM1.C, D6.2 (A), D7.C, H1.1, H2.1, H3.1, H4.1, J2.2, J3.2 (Ext), J4.3, J6.1, P1.2, R1.2, R2.2, R3.1, R11.1, R17.2, U1.4 (V-), U3.3 (GND), U3.7 (SD), U4.3 (IN+), U5.3 (+), U5.5 (+), U5.10 (+), U6.4 (GND), U8.2 (GND)
unnamed: C2.1, R6.2, S1.1
unnamed: C23.1, R25.1, R26.1
unnamed: C26.1, R27.2, R28.1
unnamed: D1.A, R12.2
unnamed: D1Dout1.A, R8.2
unnamed: D2.C, D4.A, U5.7
unnamed: D2PWM1.A, R9.2
unnamed: D3.C, D5.A, U5.14
unnamed: D4.C, D5.C, R23.2, R24.2, R27.1
unnamed: C30.1, D6.1 (K), J6.3, R28.2
unnamed: D7.A, R29.2
unnamed: J1.2, R2.1, R4.1, R5.1
unnamed: J1.3, R1.1
unnamed: J3.1 (In), R10.1
unnamed: J4.1, R16.2, U4.6 (OUT)
unnamed: J5.1, R17.1, R18.1, U5.9 (-)
unnamed: J5.2, R19.1, U5.1
unnamed: R3.2, RV1.3
unnamed: R11.2, RV2.3
unnamed: R13.2, RV2.1
unnamed: R18.2, R20.1, R21.1, U5.8
unnamed: RV1.2, U1.3 (INA+)
unnamed: R4.2, U1.2 (INA-)
unnamed: R5.2, U1.5 (INB+)
unnamed: R6.1, U1.6 (INB-), U1.7 (OUT_B)
unnamed: R7.1, U1.1 (OUT_A)
unnamed: C9.1, RV2.2, U2.2 (INV._INPUT)
unnamed: C7.1, R10.2, U2.3 (NON-INV._INPUT)
unnamed: C9.2, R13.1, R14.1, U2.6 (OUTPUT)
unnamed: C10.1, U3.2 (CAP+)
unnamed: C10.2, U3.4 (CAP-)
unnamed: R14.2, R15.1, R16.1, U4.2 (IN-)
unnamed: R19.2, R22.1, U5.2 (-)
unnamed: D2.A, R20.2, R23.1, U5.6 (-)
unnamed: R21.2, U5.12 (+)
unnamed: D3.A, R24.1, U5.13 (-)
unnamed: C22.1, U6.5 (CFLY+)
unnamed: C22.2, U6.3 (CFLY-)
unnamed: C23.2, U7.9 (EN1)
unnamed: R25.2, U7.10 (EN2)
unnamed: R26.2, U7.11 (EN3)
unnamed: R22.2, U7.7 (Q4)
VCC: C1.1, C29.1, C31.1, J1.1, J2.1, J6.2, P1.1, R8.1, R9.1, R29.1, RV1.1, U1.8 (V+), U8.1 (IN), U8.3 (EN)

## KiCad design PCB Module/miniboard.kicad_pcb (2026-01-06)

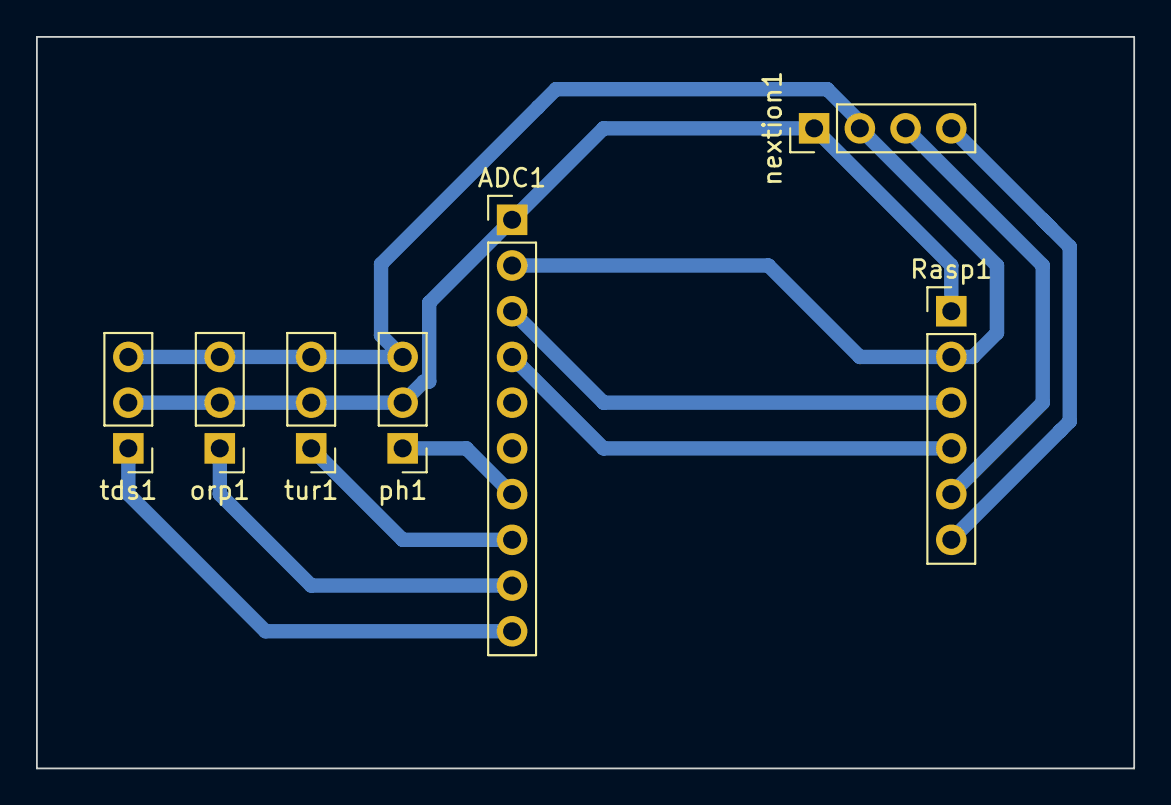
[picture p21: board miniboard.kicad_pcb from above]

Board: 2 copper layers, 61.0 x 40.6 mm, 7 parts (0 on the bottom side), 10 nets.

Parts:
ADC1: Conn_01x10_Pin; PinHeader_1x10_P2.54mm_Vertical
Rasp1: Conn_01x06_Pin; PinHeader_1x06_P2.54mm_Vertical
nextion1: Conn_01x04_Pin; PinHeader_1x04_P2.54mm_Vertical
orp1: Conn_01x03_Pin; PinHeader_1x03_P2.54mm_Vertical
ph1: Conn_01x03_Pin; PinHeader_1x03_P2.54mm_Vertical
tds1: Conn_01x03_Pin; PinHeader_1x03_P2.54mm_Vertical
tur1: Conn_01x03_Pin; PinHeader_1x03_P2.54mm_Vertical

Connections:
+5V: ADC1.1, Rasp1.1, nextion1.1, orp1.2, ph1.2, tds1.2, tur1.2
GND: ADC1.2, Rasp1.2, nextion1.2, orp1.3, ph1.3, tds1.3, tur1.3
unnamed: ADC1.3, Rasp1.3
unnamed: ADC1.4, Rasp1.4
unnamed: ADC1.7, ph1.1
unnamed: ADC1.8, tur1.1
unnamed: ADC1.9, orp1.1
unnamed: ADC1.10, tds1.1
unnamed: Rasp1.5, nextion1.3
unnamed: Rasp1.6, nextion1.4

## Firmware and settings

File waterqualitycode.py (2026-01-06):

import board
import busio
import adafruit_ads1x15.ads1115 as ADS
from adafruit_ads1x15.analog_in import AnalogIn
import time
import serial

# -----------------------------------------
#  I2C Setup for ADS1115
# -----------------------------------------
i2c = busio.I2C(board.SCL, board.SDA)
ads = ADS.ADS1115(i2c)
ads.gain = 1     # 4.096V full-scale

# -----------------------------------------
#  Sensor Channel Mapping (Correct)
# -----------------------------------------
ph_sensor = AnalogIn(ads, 0)        # Channel A0
turbidity_sensor = AnalogIn(ads, 1) # Channel A1
orp_sensor = AnalogIn(ads, 2)       # Channel A2
tds_sensor = AnalogIn(ads, 3)       # Channel A3

# -----------------------------------------
#  pH Calibration Values (Adjust if needed)
# -----------------------------------------
ph_4_voltage = 2.056
ph_7_voltage = 1.563

# -----------------------------------------
#  Serial Ports
# -----------------------------------------
ser_nextion = serial.Serial('/dev/ttyS0', 9600, timeout=1)      # For Nextion HMI
ser_pc = serial.Serial('/dev/ttyUSB0', 115200, timeout=1)       # To PC via USB

eof = b"\xff\xff\xff"   # Nextion command terminator

# -----------------------------------------
#  Main Loop
# -----------------------------------------
try:
    while True:

        # -------- pH Sensor Calculation ----------
        raw_ph = ph_sensor.value
        voltage_ph = (raw_ph * 4.096) / 32767.0

        slope = (ph_7_voltage - ph_4_voltage) / 3
        offset = ph_4_voltage - (slope * 4)
        ph_value = (voltage_ph - offset) / slope

        # -------- Turbidity Calculation ----------
        raw_tur = turbidity_sensor.value
        turbidity = (raw_tur / 65535) * 1000  # NTU

        # -------- ORP Calculation ----------
        raw_orp = orp_sensor.value
        orp_mV = (raw_orp / 65535) * 600  # mV

        # -------- TDS Calculation ----------
        raw_tds = tds_sensor.value
        tds_ppm = (raw_tds / 65535) * 5000  # ppm

        # -------- Prepare Display String ----------
        sensor_string = (
            f"pH={ph_value:.2f}, "
            f"Turbidity={turbidity:.2f}NTU, "
            f"ORP={orp_mV:.2f}mV, "
            f"TDS={tds_ppm:.2f}ppm\n"
        )

        # -------- Send to PC via USB Serial (PySerial) --------
        ser_pc.write(sensor_string.encode())
        print("PC USB →", sensor_string.strip())

        # -------- Send to Nextion Display --------
        ser_nextion.write(f'page0.t5.txt="{ph_value:.2f}"'.encode() + eof)
        ser_nextion.write(f'page0.t6.txt="{turbidity:.2f}"'.encode() + eof)
        ser_nextion.write(f'page0.t7.txt="{orp_mV:.2f}"'.encode() + eof)
        ser_nextion.write(f'page0.t8.txt="{tds_ppm:.2f}"'.encode() + eof)

        time.sleep(1)

except KeyboardInterrupt:
    print("\nStopped by user")

except Exception as e:
    print("Error:", e)
